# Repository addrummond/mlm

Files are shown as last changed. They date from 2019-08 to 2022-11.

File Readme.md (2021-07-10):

# Mimimalist Light Meter

    

## User manual

The user manual is [here](https://github.com/addrummond/mlm/blob/master/manual/manual.md).

## Overview

This is a simple ambient light meter using a Liteon LTR-303ALS light sensor and
an EFM32 Tiny Gecko ARM microcontroller. It is powered by a single CR2032 coin cell.
The firmware is written in C and the PCB is designed using KiCad. Readings are
displayed using a circle of 24 LEDs, with two additional LEDs indicating ±⅓ stop
adjustments. The user interface consists of three touch sensitive pads.

The goal of the project is to make available a simple, compact and inexpensive
light meter suitable for analogue photography. 

Dimensions: 87×56x7.5mm

The bottom side of the PCB (the side with no components mounted) is intended to
be used as the top panel of the case. This works best with a standard 1.6mm PCB
thickness.

The case is designed for 3D printing. It's best to use multi-jet fusion, as PLA
and ABS are usually not very light tight. (You could use PLA/ABS and then paint
the inside of the case black.) The STL file and Fusion 360 design for the case
are in the `case` directory. The PCB attaches to the case using five M1.6 4mm
countersunk screws. The dimples under the LEDs should be painted white and then
given a gloss varnish. A 10×10×2mm piece of transparent acrylic should be glued
in place over the sensor window. (If you don't add this, adjust
`WINDOW_ATTENUATION_STOPS` in `config.h`.)

The device functions as a reflective light meter. The same design could be
adapted for a spot meter or incident light meter by placing a lens or diffuser
over the sensor.

The LTR-303ALS integrates over a period of 50-400ms, which is far too long for
effective flash metering. A different design would therefore be required for
this purpose (probably using a discrete photodiode).

## Build notes

See `firmware/Readme.md` for notes on the dev toolchain.

Note that a recent (as of June 2020) development version of KiCad will be
required to open the board and schema files. Version 5.99.0-3928-g3c8396cd0 is
known to work. Each component in the schematic has a `MAN` (manufacturer) and
`MPN` (manufacturer part number) property.

I recommend using the [interactive BOM](https://github.com/openscopeproject/InteractiveHtmlBom) plugin for KiCad to aid manual placement of components.

## Known issue

* LEDs a little dim in bright daylight.

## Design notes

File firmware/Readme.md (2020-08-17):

## Development notes

The project builds using the
[GNU ARM embedded toolchain](https://developer.arm.com/tools-and-software/open-source-software/developer-tools/gnu-toolchain/gnu-rm/downloads)
and GNU make.

Production build:

```sh
cd firmware
make out.elf
```

Development build:

```sh
cd firmware
DEBUG=1 make out.elf
```

[RTT](https://www.segger.com/products/debug-probes/j-link/technology/about-real-time-transfer/)
is enabled in development builds.

Other environment variables:

* `DEBUG_DEEP_SLEEP=1` Reduces the time before the device enters deep sleep mode and shows a special pattern of LEDs before it does so.

* `NOGRACE=1` Removes the grace period before initial calibration (i.e. the period where the f8 LED is turned on after
power up). This is the default behavior when `DEBUG=1`.

* `GRACE=1` Overrides the aforementioned default behavior when `DEBUG=1`.

* `NO_RTT=1` Disables RTT (already disabled unless `DEBUG=1`).

* `LEDS_WRONG_WAY_ROUND=1` Set this if you have soldered all of the LEDs the 'wrong' way round. (As every LED lead is connected to a GPIO pin, it does not really matter which way round the LEDs are as long as they have a consistent orientation.)

## Debugging using JLink

I have been using the built-in JLink debugger of the [STK3200](https://www.silabs.com/products/development-tools/mcu/32-bit/efm32-zero-gecko-starter-kit).
These instruction should work for other SiLabs EFM32 series dev kits and for a real JLink probe.
When using one of the SiLabs dev kits, you'll first have to open up Simplicity Studio
and set the debug mode of the kit to 'out'.
You can download the JLink command line tools from [Segger's website](https://www.segger.com/downloads/jlink/#J-LinkSoftwareAndDocumentationPack).

Start JLink GDB server as follows:

    JLinkGDBServer -if SWD -Device EFM32TG108F32

Start gdb using

    arm-none-eabi-gdb

Commands for setting up semihosting are in `.gdbinit` in the `firmware` dir.
They'll be run automatically if you start GDB from within this dir.

Use RTT (https://www.segger.com/jlink-rtt.html) to log debug output. See
functions defined in firmware/rrt/SEGGER_RTT.h (e.g. `SEGGER_RTT_printf`).
RTT functions are included via firmware/rtt.h which provides an rtt_init()
function that wraps RTT initialization logic and stubs for RTT functions
when DEBUG mode is off.

To view RTT output:

    JLinkRTTClient

It seems to hook up with the JLink GDB server without the aid of any
parameters.

## Notes

* An unfortunate feature of the TPS610981 boost converter is that it has a
  tendency to misbehave during startup if there is an initial current spike and
  the power source has a high impedance. Coin cells, especially when at less
  than full capacity, have a relatively high impedance. I am still not sure
  exactly what happens, but the issue appears to be the same (unsolved) one that
  you can read about in [this forum
  post](http://e2e.ti.com/support/power-management/f/196/t/827996?TPS610981-Converter-in-latch-up-mode).
  From the point of view of using the device normally, I believe that I've
  solved this problem by bumping up the input capacitance slightly and making
  firmware changes to reduce current spiking on startup. However, when the
  debugger is connected, things are less predictable. I recommend using the 3.3V
  power out of the STK3200 while programming and debugging the device. (Just
  attach a crocodile clip to the coin cell retainer.) If you really want to use
  battery power while debugging, it's best to power up the device first and then
  connect the debugging leads. Even then, you may occasionally find that the
  TPS610981 gets into a weird state. If this happens, just remove the cell. In
  this state, the cell appears to be effectively shorted, so it can take it a
  little while to recover.

* It is necessary to do a `monitor reset` and `monitor halt` before loading new
firmware, since otherwise things like counters and interrupts can get screwed
up even though most of the code appears to run normally.

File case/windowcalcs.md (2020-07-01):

**Note**: These calculations are for a larger window than the one in the current design. See `case/fov/fov/__init__.py` for up to date calculations.

```
              ↔ 10mm
      -------------------- <-  upper surface of window
    2mm ↕     ↔ 7.2mm
        ---------------    <- lower surface of window
              |
       3.4mm↕ |  
 sensor ->  __|__ ↔ 0.305mm
            |   | ↕ 0.7mm
---------------------------------  <- pcb surface
```

Angle of view (half angle):

```
atan((7.2/2)/3.4) = 46.637°
```

Refractive indices:

```
air: 1.00029
acrylic: 1.4901
```

Refraction example:

```
angle of incidence = 40°
angle of refraction = 25.5626°
d = 2 * tan(25.5626°) = 0.957mm
```

Conclusion: effect of refraction should be negligible.

The LTR303 datasheet has a graph of relative responsivity against viewing angle.
Approximately 27.18% of the area of this graph is outside the 46.637° viewing
angle allowed by the window.

```
log2(1 + 0.2718) = 0.3468
```

Thus, the estimated attenuation from the restrictions imposed on angle of
view by the window is 0.3468 stops.

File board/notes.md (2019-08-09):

LED:

https://www.digikey.co.uk/product-detail/en/samsung-semiconductor-inc/SCP8RT78HPL1RLS06E/1510-1497-1-ND/6052660

https://www.digikey.co.uk/product-detail/en/osram-opto-semiconductors-inc/GW-SBLMA2.EM-HPHR-XX57-1-65-R18/475-3224-1-ND/6569722

35mm diameter circle (24 LEDs):

(0, 100.0, 82.5)
(345, 104.52933328929412, 83.0962980399413)
(330, 108.75, 84.84455543377233)
(315, 112.37436867076458, 87.62563132923542)
(300, 115.15544456622767, 91.25)
(285, 116.9037019600587, 95.47066671070588)
(270, 117.5, 100.0)
(255, 116.9037019600587, 104.52933328929412)
(240, 115.15544456622767, 108.75)
(225, 112.37436867076458, 112.37436867076458)
(210, 108.75, 115.15544456622767)
(195, 104.52933328929412, 116.9037019600587)
(180, 100.0, 117.5)
(165, 95.47066671070588, 116.9037019600587)
(150, 91.25, 115.15544456622769)
(135, 87.62563132923542, 112.37436867076458)
(120, 84.84455543377233, 108.75)
(105, 83.0962980399413, 104.52933328929412)
(90, 82.5, 100.0)
(75, 83.0962980399413, 95.4706667107059)
(60, 84.84455543377233, 91.25)
(45, 87.62563132923542, 87.62563132923542)
(30, 91.25, 84.84455543377233)
(15, 95.47066671070588, 83.0962980399413)

https://www.digikey.co.uk/product-detail/en/silicon-labs/EFM32TG210F8-QFN32/336-4548-2-ND/2508074

45 x 73
5 x 81

battery clip:

https://www.digikey.co.uk/product-detail/en/mpd-memory-protection-devices/BK-6219-TR/BK-6219-TR-ND/8119239

EFM32TG108

CR2016 cell holder

https://www.digikey.com/product-detail/en/mpd-memory-protection-devices/BLP2016SM-GTR/BLP2016SM-GCT-ND/5430470

Neat looking boost converter:

http://www.farnell.com/datasheets/71091.pdf

Very cheap 0603 LED:

https://www.digikey.co.uk/product-detail/en/wurth-electronics-inc/150060RS75000/732-4978-1-ND/4489899

Set ISO
Set aperture
Set shutter speed

Fix one; other two vary via slider.

Showing an exposure:

LEDs for relevant aperture and shutter speed are on.
LED for ISO flashes.

Compensation shown by

## Dimension stuff

Top layer component heights:

    EFM32 0.95 (max assuming 0.05mm tolerance)
    button height above board 0.65
    protrusion from top plate for button: 0.2

Bottom layer component heights:

    0.7 (light sensor)
    2.28 (battery clip max within tolerance)
    USE 2.6 mm standoff

PCB thickness:

    0.65 (assuming 0.05mm tolerance)

Total height:

    3.88mm

With 1mm case side thickness:

    5.88mm

Screws:

    https://www.accu.co.uk/en/binding-screws/72058-SBI-4-40-1-8-A2
    https://www.accu.co.uk/en/hexagon-nuts/36760-HPN-4-40-A2
    https://www.mouser.co.uk/ProductDetail/Keystone-Electronics/4881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

    |  board 0.6mm
    |
    ------
    |  screw hole thing 0.92mm
    |
    |
    |
    ------
    |
    |  gap (0)
    |
    ------
    |  rest 0.38mmm
    |
    |
    -----
    |
    |  screw head within floor extension 0.98mm
    |
    ------
    |
    |  screw head within floor 0.75mm 1.73mm
    |

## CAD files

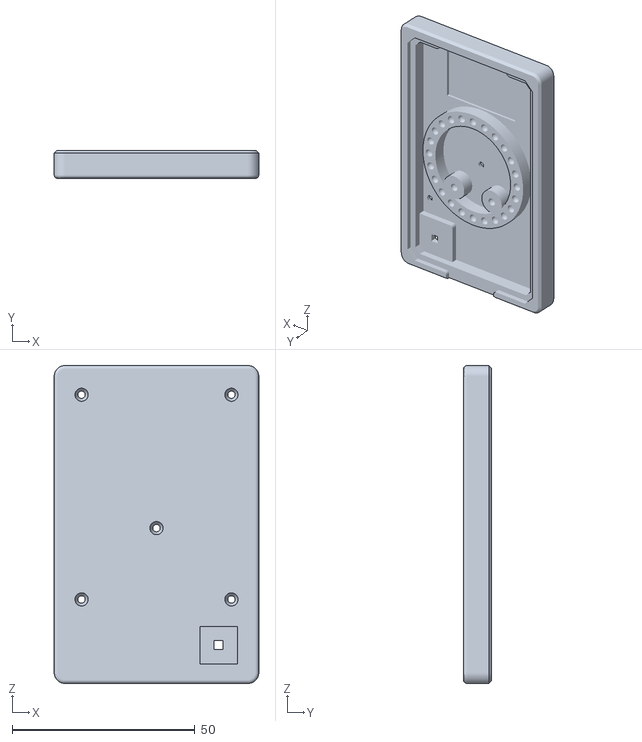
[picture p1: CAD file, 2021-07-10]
case/case.stl
56.0 x 7.70 x 87.0

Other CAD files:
case/case.f3d

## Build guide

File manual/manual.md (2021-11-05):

# Manual

## Overview

**Mode:** reflective

**Range:** EV -3.5 to 19 at ISO 100

**Field of view:** 40° (horizontal FOV of 50mm lens on full frame)

## Turning the meter on

The meter does not have an on/off switch. It is always ready to detect a press
of the center pad. (It cannot be worken up by pressing the left or right pads.)

Due to careful use of low energy sleep modes, the battery drains very slowly
when the meter is not in use.

After around an hour without use, the meter goes into a deeper sleep mode.
To wake the meter from this mode, you may need to hold down the center pad for
up to one second.

## Basic operation

Take a reading by pointing the sensor window towards the subject and 
pressing and holding the center pad.

While the reading is in process, the lights on the wheel cycle rapidly. Once the
reading is complete, the lights stop cycling and the reading is displayed.

Let go of the center pad once the reading is complete.

Read off the aperture and shutter speed.

## Battery

The meter is powered by a single CR2032 coin cell. The cell should be inserted
with the positive side facing away from the circuit board.

When a new battery is inserted, the light for f8 will turn on for around 10
seconds. When this light goes out, initial calibration of the touch pads is
performed (which takes a fraction of a second). For best results, rest the meter
on the case while the light is still on, and wait for a second after the light
goes out before touching the meter.

## Changing the aperture and shutter speed.

While a reading is displayed, tap the left or right pad to move
beetween equivalent exposures. For example, if the exposure shown is 1/60 at f8,
tapping the left pad will switch to 1/125 at f5.6.

Out of the box, the first reading is displayed with the aperture fixed at f8
(unless a very bright or very dark scene makes this impossible). On subsequent
readings, the meter attempts to preserve the last selected aperture.

## Third stops

The two lights inside the wheel indicate changes of ±⅓ stop. The light on the
left means “go ⅓ stop counterclockwise”; the light on the right
means “go ⅓ stop clockwise”.

**Example:** the exposure shown is 1/60 at f8 and the right light is on. This
indicates that the following are correct exposures:

* 1/80 at f8 (adjusting the shutter speed by ⅓ stop), and
* 1/60 at f9 (adjusting the aperture by ⅓ stop).

## Reading display timeout

After a reading has been displayed for around 20 seconds, the meter will
automatically sleep. Tap the center pad to wake the meter up and display the
last reading.

## Changing the ISO

The meter is set to ISO 100 by default. To change the ISO, press the left and
right pads simultaneously while the meter is displaying a reading. The currently
set ISO is indicated by a single pulsing light. Tap the left and right pads to
adjust, then tap the center pad to confirm and return to the reading display.

All ISO numbers shown on the inside of the wheel are full stop ISOs. Third stop
ISOs are shown as bullets. You can select a third stop ISO that has no
corresponding bullet by selecting the nearest full stop ISO and then holding the
left or right pad until one of the ±⅓ stop indication lights turns on. The left
light means “go ⅓ stop counterclockwise” (i.e. decrease the ISO number
slightly), while the right light means “go ⅓ stop clockwise” (i.e. increase the
ISO number slightly).

When a reading is in progress, one light stays on uninterrupted while the others
cycle. This light indicates the currently selected ISO (or the nearest full stop
ISO to it).

## Special display of low light exposures

Using two indicator lights (one for aperture and one for shutter speed), the
wheel can show exposures down to -⅓EV at any given ISO. As the lower range of
the meter is -3.5EV at ISO 100, this means that at ISOs below 1600, the EV can
be low enough that no corresponding exposure can be displayed in the usual way.
In this circumstance, the meter indicates exposures longer than one second by
turning on three shutter speed lights rather than one. The number corresponding
to the middle light should be interpreted as a number of seconds. For example,
if the lights for 2, 4 and 8 are on, this indicates an exposure of four
seconds.

## Out of range indication

If the scene is too bright or too dark for the meter, the three lights at the
top of the wheel (corresponding to f5.6, f8 and f11) turn on simultaneously.

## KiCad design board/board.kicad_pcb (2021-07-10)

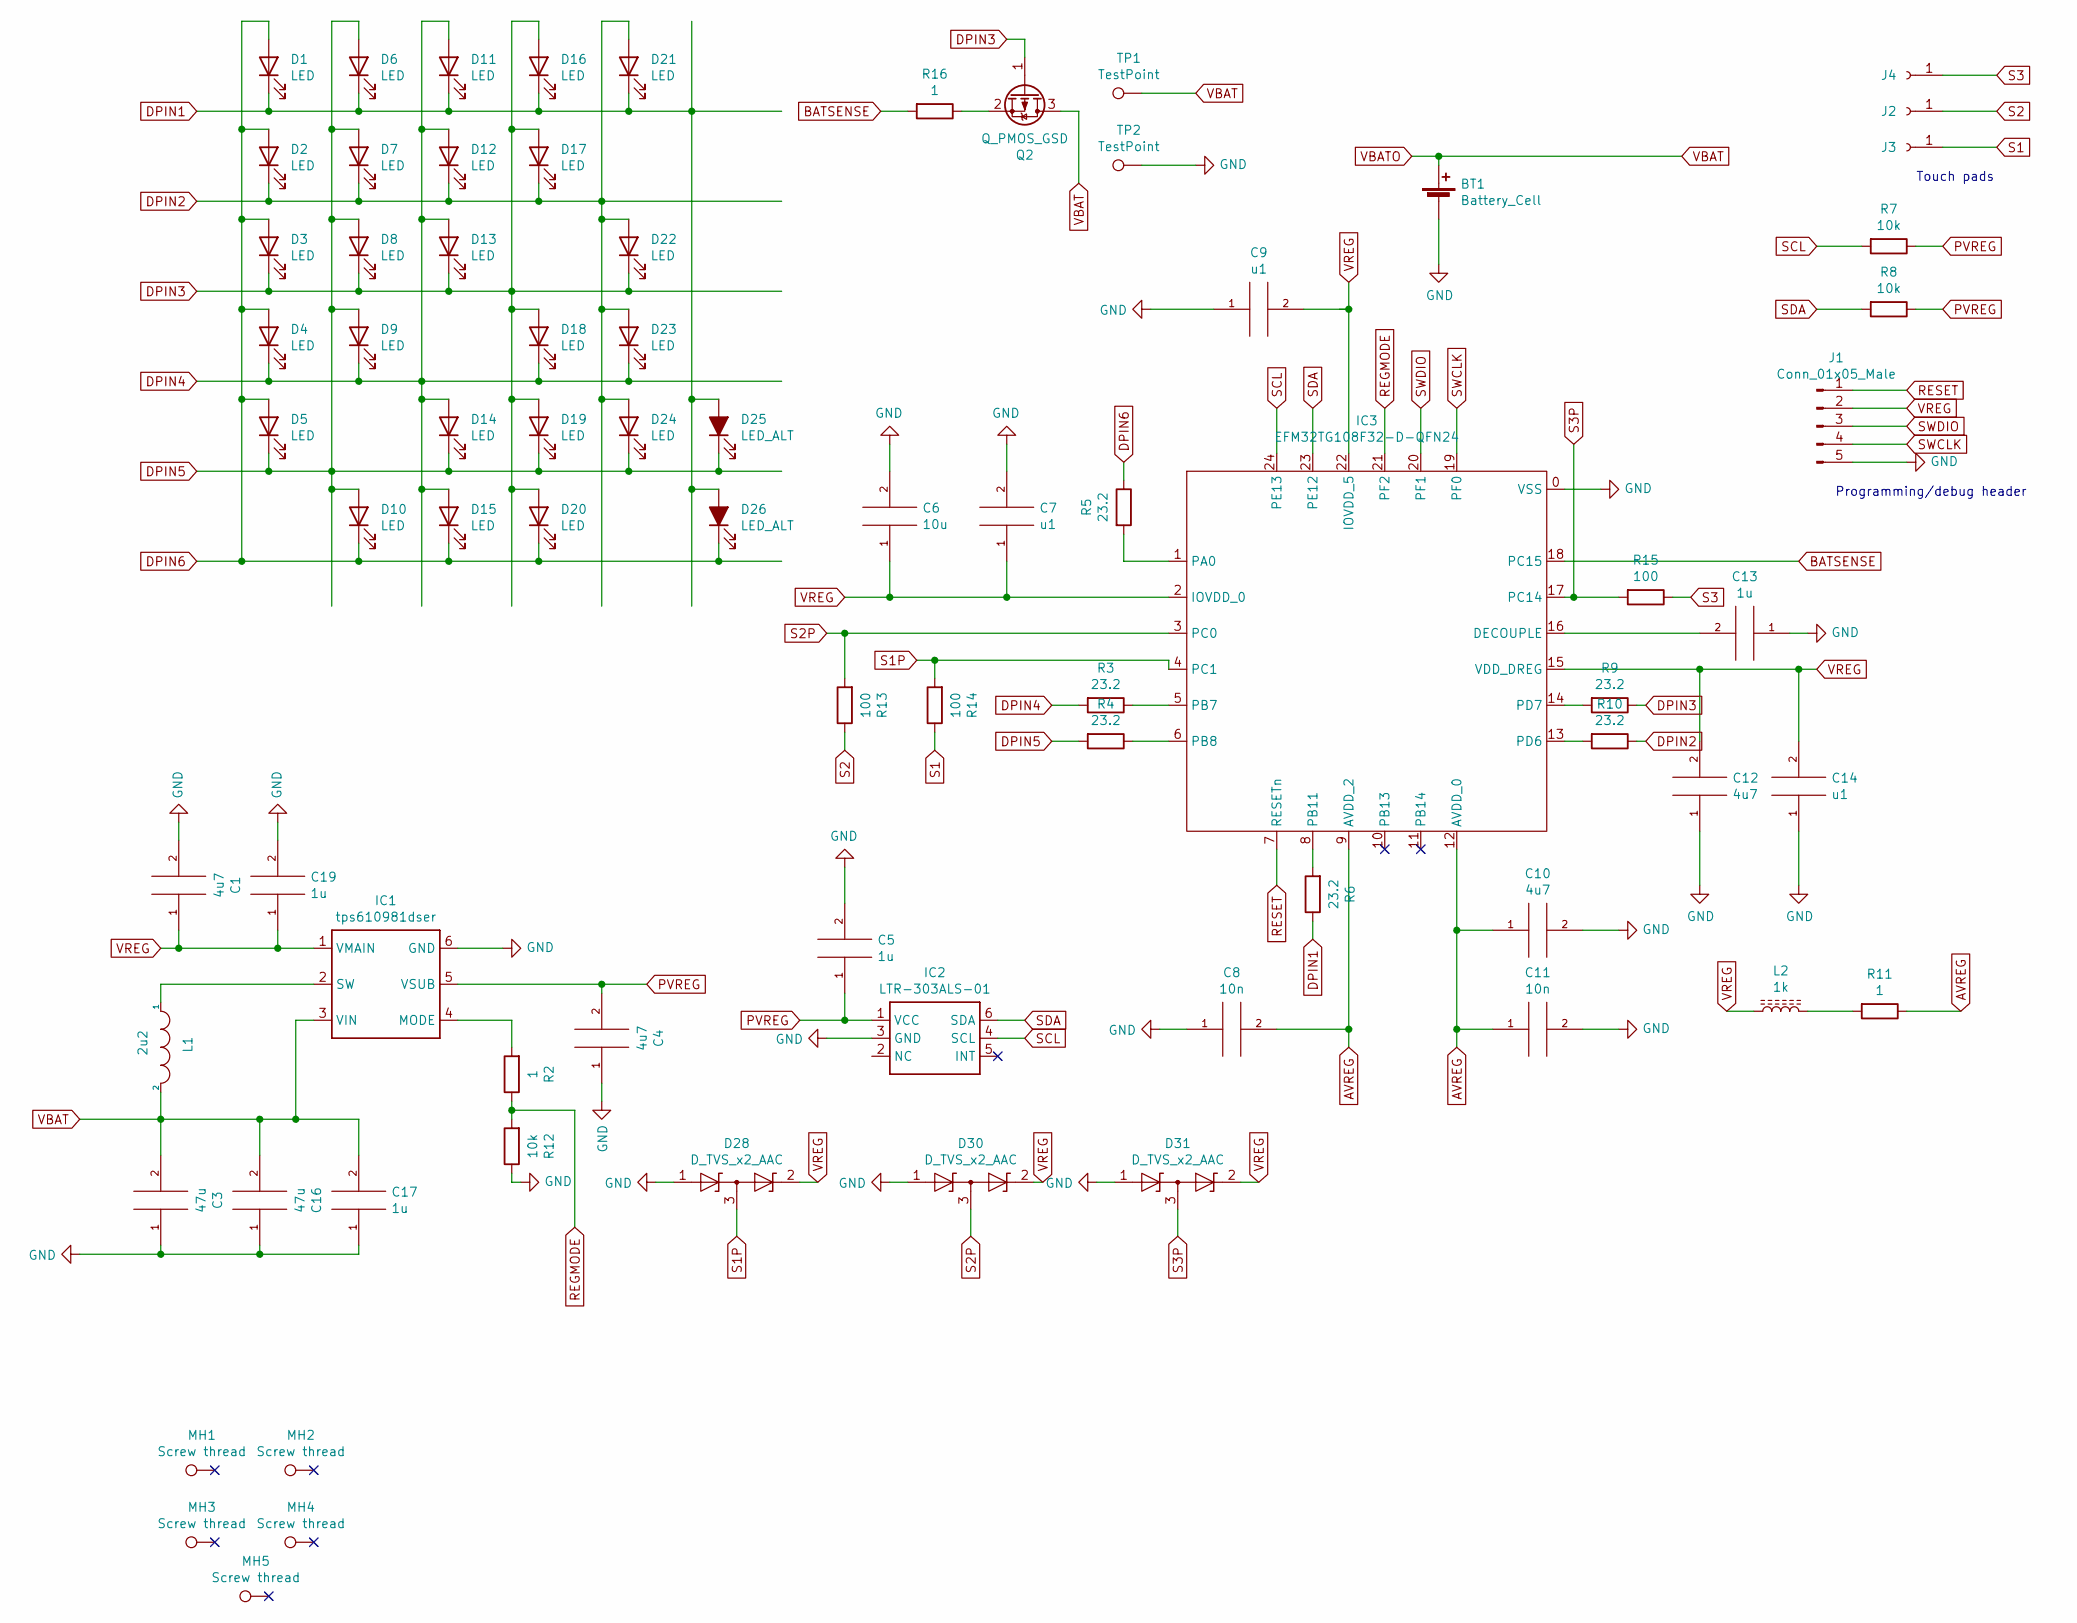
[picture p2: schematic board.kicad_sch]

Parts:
BT1: Battery_Cell; BK-5067; MPN BK-5067
C1, C4, C10, C12: 4u7; 0603; MPN C0603C475K9PAC7411
C3, C16: 47u; 0603; MPN GRM188R60G476ME15D
C5, C13, C17, C19: 1u; 0603; MPN CL10B105KP8NNNC
C6: 10u; 0603; MPN JMK107ABJ106MA-T
C7, C9, C14: u1; 0603; MPN 885012206020
C8, C11: 10n; 0603; MPN CL10B103KB8NNNC
D1, D2, D3, D4, D5, D6, D7, D8, D9, D10, D11, D12, D13, D14, D15, D16, D17, D18, D19, D20, D21, D22, D23, D24: LED; dual0402; MPN IN-S42BT5B
D25, D26: LED_ALT; dual0402; MPN IN-S42BT5B
D28, D30, D31: D_TVS_x2_AAC; SOT-23; MPN BAS70-04-TP
IC1: tps610981dser; tps610986; MPN TPS610981DSER
IC2: LTR-303ALS-01; LTR303ALS01; MPN LTR-303ALS-01
IC3: EFM32TG108F32-D-QFN24; EFM32TG108_QFN24; MPN EFM32TG108F32-QFN24
J1: Conn_01x05_Male; M20-7910542R; MPN M20-7910542R
J2, J3, J4: TOUCHPAD
L1: 2u2; NRS4010T2R2MDGG; MPN NRS4010T2R2MDGG
L2: 1k; 0805; MPN BLM21BD102SN1D
MH1, MH2, MH3, MH4, MH5: Screw thread; 97730306330R; MPN 97730306330R
Q2: Q_PMOS_GSD; SOT-23; MPN SI2329DS-T1-GE3
R2, R11, R16: 1; 0603; MPN ERJ3RQF1R0V
R3, R4, R5, R6, R9, R10: 23.2; 0603; MPN ERJ-3EKF23R2V
R7, R8, R12: 10k; 0603; MPN RNCP0603FTD10K0
R13, R14, R15: 100; 0603; MPN RC0603FR-07100RL
TP1, TP2: TestPoint; TestPoint_Pad_D1.5mm

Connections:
AVREG: C8.2, C10.1, C11.1, IC3.9 (AVDD_2), IC3.12 (AVDD_0), R11.1
BATSENSE: IC3.18 (PC15), R16.2
DPIN1: D1.1 (K), D6.1 (K), D11.1 (K), D16.1 (K), D21.1 (K), D25.2 (A), D26.2 (A), R6.1
DPIN2: D2.1 (K), D7.1 (K), D12.1 (K), D17.1 (K), D21.2 (A), D22.2 (A), D23.2 (A), D24.2 (A), R10.1
DPIN3: D3.1 (K), D8.1 (K), D13.1 (K), D16.2 (A), D17.2 (A), D18.2 (A), D19.2 (A), D20.2 (A), D22.1 (K), Q2.1 (G), R9.1
DPIN4: D4.1 (K), D9.1 (K), D11.2 (A), D12.2 (A), D13.2 (A), D14.2 (A), D15.2 (A), D18.1 (K), D23.1 (K), R3.2
DPIN5: D5.1 (K), D6.2 (A), D7.2 (A), D8.2 (A), D9.2 (A), D10.2 (A), D14.1 (K), D19.1 (K), D24.1 (K), D25.1 (K), R4.2
DPIN6: D1.2 (A), D2.2 (A), D3.2 (A), D4.2 (A), D5.2 (A), D10.1 (K), D15.1 (K), D20.1 (K), D26.1 (K), R5.1
GND: BT1.2 (-), C1.2, C3.1, C4.1, C5.2, C6.2, C7.2, C8.1, C9.1, C10.2, C11.2, C12.1, C13.1, C14.1, C16.1, C17.1, C19.2, D28.1 (A1), D30.1 (A1), D31.1 (A1), IC1.6 (GND), IC2.3 (GND), IC3.0 (VSS), J1.5, R12.1, TP2.1
unnamed: C13.2, IC3.16 (DECOUPLE)
unnamed: IC1.2 (SW), L1.1
unnamed: IC1.4 (MODE), R2.2
unnamed: IC3.1 (PA0), R5.2
unnamed: IC3.5 (PB7), R3.1
unnamed: IC3.6 (PB8), R4.1
unnamed: IC3.8 (PB11), R6.2
unnamed: IC3.13 (PD6), R10.2
unnamed: IC3.14 (PD7), R9.2
unnamed: L2.2, R11.2
unnamed: Q2.2 (S), R16.1
PVREG: C4.2, C5.1, IC1.5 (VSUB), IC2.1 (VCC), R7.1, R8.1
REGMODE: IC3.21 (PF2), R2.1, R12.2
RESET: IC3.7 (RESETn), J1.1
S1: J3.1, R14.1
S1P: D28.3 (common), IC3.4 (PC1), R14.2
S2: J2.1, R13.1
S2P: D30.3 (common), IC3.3 (PC0), R13.2
S3: J4.1, R15.1
S3P: D31.3 (common), IC3.17 (PC14), R15.2
SCL: IC2.4 (SCL), IC3.24 (PE13), R7.2
SDA: IC2.6 (SDA), IC3.23 (PE12), R8.2
SWCLK: IC3.19 (PF0), J1.4
SWDIO: IC3.20 (PF1), J1.3
VBAT: BT1.1 (+), C3.2, C16.2, C17.2, IC1.3 (VIN), L1.2, Q2.3 (D), TP1.1
VREG: C1.1, C6.1, C7.1, C9.2, C12.2, C14.2, C19.1, D28.2 (A2), D30.2 (A2), D31.2 (A2), IC1.1 (VMAIN), IC3.2 (IOVDD_0), IC3.15 (VDD_DREG), IC3.22 (IOVDD_5), J1.2, L2.1

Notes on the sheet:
Programming/debug header
Touch pads

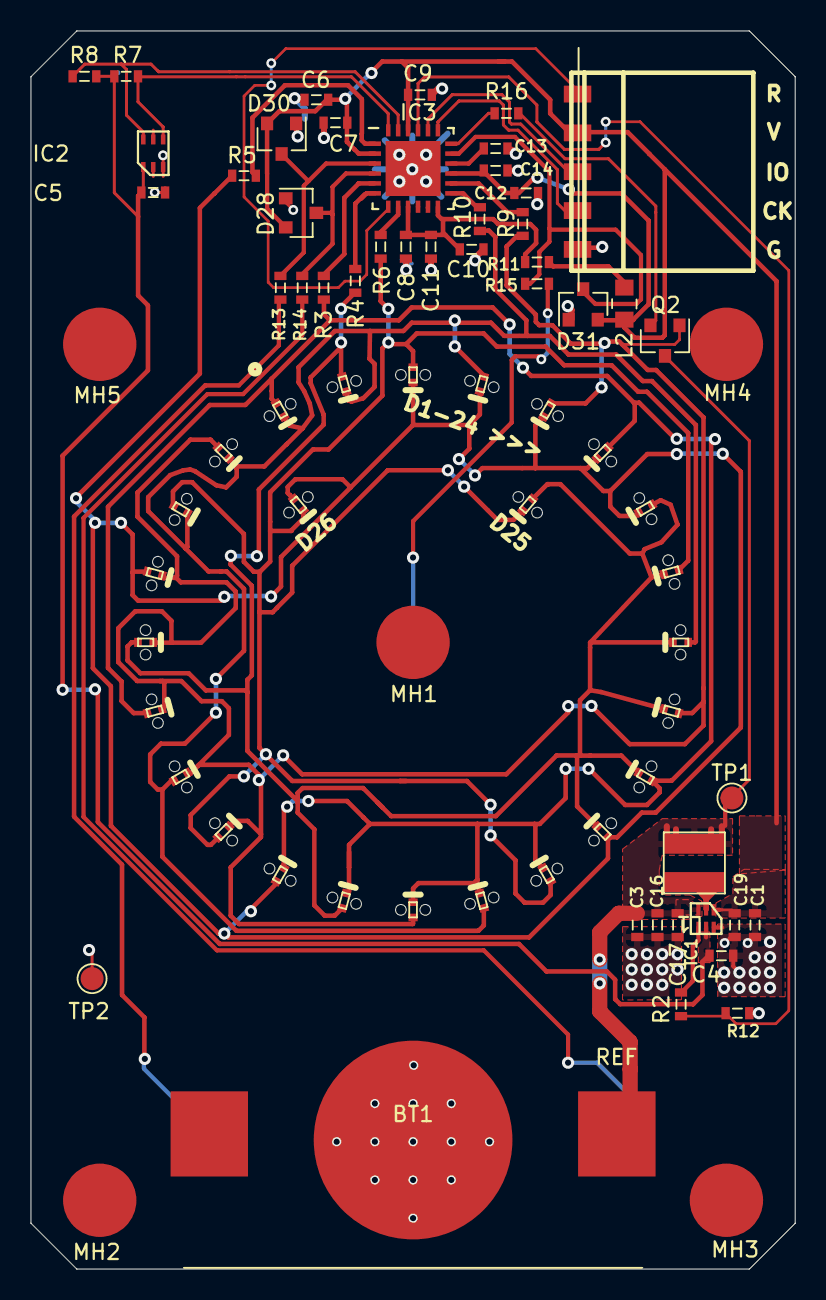
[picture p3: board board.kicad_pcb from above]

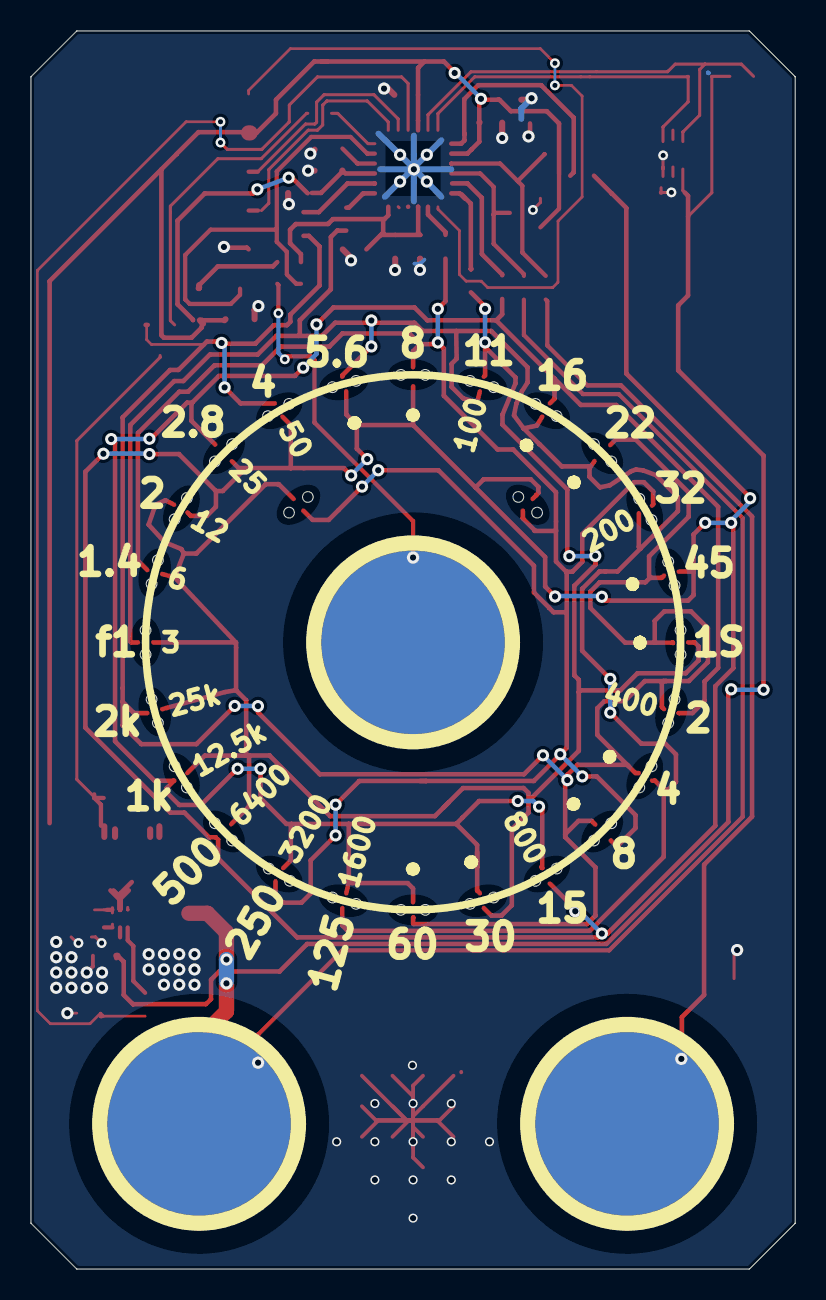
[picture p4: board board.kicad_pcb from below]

Board: 2 copper layers, 50.0 x 81.0 mm, 78 parts (29 on the bottom side), 35 nets.

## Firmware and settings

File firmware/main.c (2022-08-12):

#include <config.h>

#include <batsense.h>
#include <capsense.h>
#include <em_acmp.h>
#include <em_chip.h>
#include <em_cmu.h>
#include <em_dbg.h>
#include <em_emu.h>
#include <em_device.h>
#include <em_emu.h>
#include <em_gpio.h>
#include <em_pcnt.h>
#include <em_prs.h>
#include <em_rmu.h>
#include <em_rtc.h>
#include <em_timer.h>
#include <em_wdog.h>
#include <init.h>
#include <iso.h>
#include <leds.h>
#include <myemu.h>
#include <pins.h>
#include <rtc.h>
#include <rtt.h>
#include <sensor.h>
#include <state.h>
#include <stdbool.h>
#include <stdint.h>
#include <tempsensor.h>
#include <time.h>
#include <units.h>
#include <util.h>

#ifdef TEST_MAIN
int test_main(void);
#endif

static void go_into_deep_sleep()
{
    SEGGER_RTT_printf(0, "Enter deep sleep (unless in DEBUG mode).\n");

    CMU_ClockEnable(cmuClock_CORELE, true);

    EMU_EM23Init_TypeDef dcdcInit = EMU_EM23INIT_DEFAULT;
    EMU_EM23Init(&dcdcInit);

    RTC_Enable(false);

    WDOG_Init_TypeDef wInit = {
        .clkSel = wdogClkSelULFRCO,
        .debugRun = true,
        .em2Run = true,
        .em3Run = true,
        .em4Block = true,
        .enable = true,
        .lock = false,
        .perSel = wdogPeriod_1k, // 1k 1kHz periods should give ~4 seconds in EM3
        .swoscBlock = false
    };

    WDOGn_Init(WDOG, &wInit);
    WDOGn_Feed(WDOG);

    RMU->CTRL &= ~0b111;
    RMU->CTRL |= 1; // limited watchdog reset

    my_emu_enter_em3(false);
}

static void go_into_deep_sleep_with_indication()
{
    // A visual indication that it's going into deep sleep mode is sometimes
    // useful for debugging.
#ifdef DEBUG_DEEP_SLEEP
    leds_all_off();
    leds_on(0b111);
    uint32_t start = leds_on_for_cycles;
    while (leds_on_for_cycles - start < RTC_RAW_FREQ)
        ;
    leds_all_off();
#endif

    go_into_deep_sleep();
}

static void go_into_fake_deep_sleep_with_indication()
{
    // A visual indication that it's going into fake deep sleep mode is sometimes
    // useful for debugging.
#ifdef DEBUG_DEEP_SLEEP
    leds_all_off();
    leds_on(0b11);
    uint32_t start = leds_on_for_cycles;
    while (leds_on_for_cycles - start < RTC_RAW_FREQ)
        ;
    leds_all_off();
#endif

    le_capsense_slow_scan();
}

static void maybe_sleep_deeper()
{
    static const int32_t DEEP_SLEEP_TIMING_FUDGE_FACTOR_NUMERATOR = 6;
    static const int32_t DEEP_SLEEP_TIMING_FUDGE_FACTOR_DENOMINATOR = 5;

    static const int32_t deep_sleep_timeout_seconds =
#ifdef DEBUG_DEEP_SLEEP
        DEEP_SLEEP_TIMEOUT_SECONDS_DEBUG_MODE;
#else
        DEEP_SLEEP_TIMEOUT_SECONDS;
#endif

#ifndef DEBUG
    if ((g_state.deep_sleep_counter++) * DEEP_SLEEP_TIMING_FUDGE_FACTOR_NUMERATOR / DEEP_SLEEP_TIMING_FUDGE_FACTOR_DENOMINATOR > deep_sleep_timeout_seconds/LE_CAPSENSE_CALIBRATION_INTERVAL_SECONDS) {
        // We've been sleeping for a while now and nothing has happened.
        // Time to go into deep sleep.
#ifdef DISABLE_DEEP_SLEEP
        go_into_fake_deep_sleep_with_indication();
#else
        go_into_deep_sleep_with_indication();
#endif
    }
#endif
}

static void handle_MODE_JUST_WOKEN()
{
    if (! g_state.watchdog_wakeup) {
        while (! check_lesense_irq_handler()) {
            maybe_sleep_deeper();

            recalibrate_le_capsense();
            SEGGER_RTT_printf(0, "EM2 snooze after calib.\n");
            my_emu_enter_em2(true); // true = restore oscillators, clocks and voltage scaling
            SEGGER_RTT_printf(0, "Woken up [2]!\n");
        }

        disable_le_capsense();

        int v = battery_voltage_in_10th_volts();
        g_state.bat_known_healthy = (v >= 27);
        SEGGER_RTT_printf(0, "BKH %u %u\n", v, g_state.bat_known_healthy);
#ifdef DEBUG
        g_state.bat_known_healthy = false;
#endif

    } else {
        PCNT_Reset(PCNT0);
        reset_lesense_irq_handler_state();
        reset_led_state();
        reset_capsense_state();
        SEGGER_RTT_printf(0, "Watchdog wake\n");
    }

    g_state.watchdog_wakeup = false;
    g_state.deep_sleep_counter = 0;

    // If it was a brief tap on the button, go to AWAKE_AT_REST.
    // If they've held the button down for a little bit,
    // start doing a reading. If it was a double tap, go to
    // ISO / exposure set mode.
    setup_capsense();
    press p = get_pad_press(CENTER_BUTTON, LONG_PRESS_MS);
    disable_capsense();

    rtc_init();

    if (p == PRESS_HOLD) {
        g_state.mode = MODE_DOING_READING;
    } else if (p == PRESS_TAP) {
        // It was just a tap.
        g_state.last_reading_flags |= LAST_READING_FLAGS_FRESH;
        g_state.mode = MODE_AWAKE_AT_REST;
    } else {
        SEGGER_RTT_printf(0, "Unknown but\n");
    }
}

static void handle_MODE_AWAKE_AT_REST()
{
    // Display the current reading, if any.
    if (fresh_reading_is_saved()) {
        g_state.mode = MODE_DISPLAY_READING;
        g_state.last_reading_flags &= ~(int32_t)LAST_READING_FLAGS_FRESH;
    } else {
        g_state.mode = MODE_SNOOZE;
    }
}

static void handle_MODE_SNOOZE()
{
    // Make sure LDO is off
    GPIO_PinModeSet(REGMODE_PORT, REGMODE_PIN, gpioModeDisabled, 0);

    setup_le_capsense_sleep();

    SEGGER_RTT_printf(0, "EM2 for snooze\n");
    my_emu_enter_em2(true); // true = restore oscillators, clocks and voltage scaling

    SEGGER_RTT_printf(0, "Woken!\n");
    g_state.mode = MODE_JUST_WOKEN;
}

static int shift_exposure_wheel(int n, int *ap_index, int *ss_index, bool using_long_ss)
{
    int ap = *ap_index;
    int ss = *ss_index;
    while (n != 0) {
        if (n > 0) {
            if (ap == AP_INDEX_MAX)
                break;
            if ((using_long_ss && ss == SS_INDEX_LONG_MIN) || (!using_long_ss && ss == SS_INDEX_MIN))
                break;
            ++ap;
            --ss;
            --n;
        } else {
            if (ss == SS_INDEX_MAX)
                break;
            if (ap == AP_INDEX_MIN)
                break;
            ++ss;
            --ap;
            ++n;
        }
        *ap_index = ap;
        *ss_index = ss;
    }

    return n;
}

static void handle_MODE_DISPLAY_READING()
{
    int32_t iso = iso_dial_pos_and_third_to_iso(g_state.iso_dial_pos, g_state.iso_third);
    int ap_index, ss_index, third;
    ev_iso_aperture_to_shutter(g_state.last_reading_ev, iso, g_state.last_ap, &ap_index, &ss_index, &third);
    bool using_long_ss = ss_index < SS_INDEX_MIN;
    SEGGER_RTT_printf(0, "ISOi=%u, api=%s%u, ssi=%s%u\n", iso, sign_of(ap_index), iabs(ap_index), sign_of(ss_index), iabs(ss_index));

    leds_all_off();
    set_led_throb_mask(0);
    set_led_flash_mask(0);
    leds_on(led_mask_for_reading(ap_index, ss_index, third));

    setup_capsense();

    uint32_t base_cycles = leds_on_for_cycles;
    int zero_touch_position = INVALID_TOUCH_POSITION;
    uint32_t touch_counts[] = { 0, 0, 0 };
    bool in_center_button_dead_zone = true;
    uint32_t ellapsed;
    for (unsigned i = 0;; ++i) {
        delay_ms_cyc_prepare {
            get_touch_count(0, 0, 0); // clear any nonsense value
        }
        ellapsed = delay_ms_cyc_loop(PAD_COUNT_MS);

        uint32_t count, chan;
        get_touch_count(&count, &chan, ellapsed);
        touch_counts[chan] = count;

        if (leds_on_for_cycles - base_cycles > (CENTER_BUTTON_DEAD_ZONE_MS * RTC_RAW_FREQ) / 1000)
            in_center_button_dead_zone = false;

        if (touch_counts[0] != 0 && touch_counts[1] != 0 && touch_counts[2] != 0) {
            int tp = get_touch_position(touch_counts[0], touch_counts[1], touch_counts[2]);
            
            if (tp == NO_TOUCH_DETECTED) {
                zero_touch_position = INVALID_TOUCH_POSITION;
            } else {
                base_cycles = leds_on_for_cycles;

                if (zero_touch_position == INVALID_TOUCH_POSITION) {
                    if (tp == LEFT_BUTTON || tp == RIGHT_BUTTON || tp == LEFT_AND_RIGHT_BUTTONS) {
                        // If we just have one of the left/right buttons, wait to see if the situation
                        // changes in the next split second.
                        if (tp != LEFT_AND_RIGHT_BUTTONS) {
                            uint32_t over_base = leds_on_for_cycles;
                            int misses = 0;
                            touch_counts[0] = 0, touch_counts[1] = 0, touch_counts[2] = 0;
                            for (unsigned j = 0;; ++j) {
                                delay_ms_cyc_prepare {
                                    get_touch_count(0, 0, 0); // clear any nonsense value
                                }
                                ellapsed = delay_ms_cyc_loop(PAD_COUNT_MS);

                                get_touch_count(&count, &chan, ellapsed);
                                touch_counts[chan] = count;

                                if (touch_counts[0] != 0 && touch_counts[1] != 0 && touch_counts[2] != 0) {
                                    int tp2 = get_touch_position(touch_counts[0], touch_counts[1], touch_counts[2]);
                                    if (tp2 == LEFT_AND_RIGHT_BUTTONS) {
                                        tp = tp2;
                                        break;
                                    }
                                    if (tp2 == NO_TOUCH_DETECTED) {
                                        ++misses;
                                        if (misses >= MISSES_REQUIRED_TO_BREAK_HOLD)
                                            break;
                                    } else {
                                        misses = 0;
                                    }
                                }

                                if (leds_on_for_cycles - over_base >= (DOUBLE_BUTTON_SLOP_MS * RTC_RAW_FREQ / 1000))
                                    break;

                                cycle_capsense();
                            }
                        }

                        if (tp == LEFT_AND_RIGHT_BUTTONS && get_pad_press(LEFT_AND_RIGHT_BUTTONS, ISO_LONG_PRESS_MS) == PRESS_HOLD) {
                            goto handle_double_button_press;
                        }
                        else {
                            int r = shift_exposure_wheel(tp == RIGHT_BUTTON ? 1 : -1, &ap_index, &ss_index, using_long_ss);
                            g_state.last_ap = ap_index;
                            uint32_t mask = led_mask_for_reading(ap_index, ss_index, third);
                            leds_change_mask(mask);
                            if (r != 0) {
                                uint32_t flash_mask = (mask & ~((1 << LED_MINUS_1_3_N) | (1 << LED_PLUS_1_3_N)));
                                set_led_flash_mask(flash_mask);
                                delay_ms_cyc(1000);
                                set_led_flash_mask(0);
                            }
                        }
                    } else if (tp == CENTER_BUTTON && ! in_center_button_dead_zone) {
                        goto handle_center_press;
                    }
                    zero_touch_position = tp;
                } else {
                    zero_touch_position = tp;
                }
            }            
        }

        if (leds_on_for_cycles - base_cycles >= DISPLAY_READING_TIME_SECONDS * RTC_RAW_FREQ) {
            SEGGER_RTT_printf(0, "Reading timeout\n");
            break;
        }

        cycle_capsense();
    }

    disable_capsense();
    leds_all_off();

    g_state.mode = MODE_SNOOZE;

    return;

handle_center_press:
    leds_all_off();
    press p = get_pad_press(CENTER_BUTTON, LONG_PRESS_MS);
    disable_capsense();
    if (p == PRESS_HOLD)
        g_state.mode = MODE_DOING_READING;
    else if (p == PRESS_TAP)
        g_state.mode = MODE_SNOOZE;
    return;

handle_double_button_press:
    leds_all_off();
    disable_capsense();
    g_state.mode = MODE_SETTING_ISO;
}

static void handle_MODE_SETTING_ISO()
{
    leds_all_off();

    uint32_t leds = 1 << iso_dial_pos_to_led_n(g_state.iso_dial_pos);
    set_led_throb_mask(leds);
    if (g_state.iso_third == -1)
        leds |= 1 << LED_MINUS_1_3_N;
    else if (g_state.iso_third == 1)
        leds |= 1 << LED_PLUS_1_3_N;
    leds_on(leds);

    setup_capsense();

    uint32_t base_cycles = leds_on_for_cycles;
    int zero_touch_position = INVALID_TOUCH_POSITION;
    uint32_t touch_counts[] = { 0, 0, 0 };
    for (;;) {
        delay_ms_cyc_prepare {
            get_touch_count(0, 0, 0);
        }
        uint32_t ellapsed = delay_ms_cyc_loop(PAD_COUNT_MS);
        uint32_t count, chan;
        get_touch_count(&count, &chan, ellapsed);
        touch_counts[chan] = count;

        if (touch_counts[0] != 0 && touch_counts[1] != 0 && touch_counts[2] != 0) {
            int tp = get_touch_position(touch_counts[0], touch_counts[1], touch_counts[2]);
            
            if (tp == NO_TOUCH_DETECTED) {
                zero_touch_position = INVALID_TOUCH_POSITION;
            } else {
                base_cycles = leds_on_for_cycles;

                if (zero_touch_position == INVALID_TOUCH_POSITION) {
                    if (tp == LEFT_BUTTON || tp == RIGHT_BUTTON) {
                        // Check if it's a tap or a hold, if we're on one
                        // of the ISOs that can be modified with +/- 1/3rd.
                        press p = PRESS_TAP;
                        bool cycled = false;
                        if ((tp == LEFT_BUTTON && iso_dial_pos_can_go_third_below(g_state.iso_dial_pos)) || (tp == RIGHT_BUTTON && iso_dial_pos_can_go_third_above(g_state.iso_dial_pos))) {
                            if (tp == LEFT_BUTTON) {
                                cycled = true;
                                cycle_capsense();
                            }
                        
                            p = get_pad_press(tp, ISO_LONG_PRESS_MS);
                        }

                        int mag = (tp == RIGHT_BUTTON ? 1 : -1);
                        if (p == PRESS_TAP) {
                            g_state.iso_third = 0;
                            g_state.iso_dial_pos += mag;
                            if (g_state.iso_dial_pos < 0)
                                g_state.iso_dial_pos += ISO_N_DIAL_POSITIONS;
                            else
                                g_state.iso_dial_pos %= ISO_N_DIAL_POSITIONS;
                        } else {
                            // Button press will only have registered as a hold if this is a thirdable point on the dial.
                            g_state.iso_third = mag;
                        }
                        
                        leds = 1 << iso_dial_pos_to_led_n(g_state.iso_dial_pos);
                        set_led_throb_mask(leds);
                        if (g_state.iso_third == -1)
                            leds |= 1 << LED_MINUS_1_3_N;
                        else if (g_state.iso_third == 1)
                            leds |= 1 << LED_PLUS_1_3_N;
                        leds_change_mask(leds);

                        SEGGER_RTT_printf(0, "ISO -> raw %u\n", iso_dial_pos_and_third_to_iso(g_state.iso_dial_pos, g_state.iso_third));

                        if (cycled) {
                            cycle_capsense();
                            cycle_capsense();
                        }
                    } else if (tp == CENTER_BUTTON) {
                        goto handle_center_press;
                    }
                    zero_touch_position = tp;
                } else {
                    zero_touch_position = tp;
                }
            }            
        }

        if (leds_on_for_cycles - base_cycles >= DISPLAY_READING_TIME_SECONDS * RTC_RAW_FREQ) {
            SEGGER_RTT_printf(0, "Reading timeout (ISO mode)\n");
            break;
        }

        cycle_capsense();
    }

    leds_all_off();
    disable_capsense();

    SEGGER_RTT_printf(0, "Enter MODE_SNOOZE\n");
    g_state.mode = MODE_SNOOZE;

    return;

handle_center_press:
    SEGGER_RTT_printf(0, "ISO button press\n");
    leds_all_off();
    press p = get_pad_press(CENTER_BUTTON, LONG_PRESS_MS);
    disable_capsense();
    if (p == PRESS_HOLD)
        g_state.mode = MODE_DOING_READING;
    else if (p == PRESS_TAP)
        g_state.mode = MODE_SNOOZE;
}

static uint32_t display_reading_interrupt_cycle_mask1;
static uint32_t display_reading_interrupt_cycle_mask2;
static uint32_t display_reading_interrupt_cycle_iso_mask;
static void display_reading_interrupt_cycle_interrupt_handler()
{
    if (leds_on_for_cycles % 16 != 0)
        return;

    if (leds_on_for_cycles % 32 != 0) {
        display_reading_interrupt_cycle_mask1 = (display_reading_interrupt_cycle_mask1 + 1) % LED_N_IN_WHEEL;
    }

    display_reading_interrupt_cycle_mask2 = (display_reading_interrupt_cycle_mask2 + 1) % LED_N_IN_WHEEL;

    leds_change_mask((1 << display_reading_interrupt_cycle_iso_mask) | (1 << (LED_N_IN_WHEEL - display_reading_interrupt_cycle_mask1 - 1)) | (1 << display_reading_interrupt_cycle_mask2));
}

static void handle_MODE_DOING_READING()
{
    // Light show while the reading is being done.
    leds_all_off();
    add_rtc_interrupt_handler(display_reading_interrupt_cycle_interrupt_handler);
    display_reading_interrupt_cycle_mask1 = 8;
    display_reading_interrupt_cycle_mask2 = 16;
    display_reading_interrupt_cycle_iso_mask = iso_dial_pos_to_led_n(g_state.iso_dial_pos);
    leds_on((1 << display_reading_interrupt_cycle_iso_mask) | (1 << display_reading_interrupt_cycle_mask1) | (1 << display_reading_interrupt_cycle_mask2));

    // Turn on the LDO to power up the sensor.
    GPIO_PinModeSet(REGMODE_PORT, REGMODE_PIN, gpioModePushPull, 1);
    delay_ms_cyc(10); // make sure LDO has time to start up (datasheet says 1ms startup time is typical, so 10 is more than enough)
    sensor_init();
    delay_ms_cyc(100); // sensor requires 100ms initial startup time.

    // Turn the sensor on and give it time to wake up from standby.
    sensor_turn_on(GAIN_1X);
    delay_ms_cyc(10);

    // Get the raw sensor reading.
    int32_t gain, itime;
    SEGGER_RTT_printf(0, "Waiting for sensor\n");
    sensor_wait_till_ready();
    SEGGER_RTT_printf(0, "Sensor ready\n");
    sensor_reading sr = sensor_get_reading_auto(&gain, &itime);
    g_state.last_reading = sr;
    g_state.last_reading_itime = itime;
    g_state.last_reading_gain = gain;

    // Convert the raw reading to an EV value.
    int32_t lux = sensor_reading_to_lux(sr, gain, itime);
    int32_t ev = lux_to_reflective_ev(lux);
    g_state.last_reading_ev = ev;
    SEGGER_RTT_printf(0, "READING g=%u itime=%u c0=%u c1=%u lux=%u/%u (%u) ev=%s%u/%u (%u)\n", gain, itime, sr.chan0, sr.chan1, lux, 1<<EV_BPS, lux>>EV_BPS, sign_of(ev), iabs(ev), 1<<EV_BPS, ev>>EV_BPS);

    g_state.led_brightness_ev_ref = ev;

    // Turn the LDO off to power down the sensor.
    GPIO_PinModeSet(REGMODE_PORT, REGMODE_PIN, gpioModeInput, 0);

    remove_rtc_interrupt_handler(display_reading_interrupt_cycle_interrupt_handler);
    leds_all_off();

    // If they're still holding down the button, display the reading
    // indefinitely until the button is released, then go into the
    // regular display reading mode.
    setup_capsense();
    uint32_t chans[] = { 0, 0, 0 };
    do {
        delay_ms_cyc_prepare {
            get_touch_count(0, 0, 0); // clear any nonsense value
        }
        uint32_t ellapsed = delay_ms_cyc_loop(PAD_COUNT_MS);
        uint32_t count, chan;
        get_touch_count(&count, &chan, ellapsed);
        chans[chan] = count;
        cycle_capsense();
    } while (chans[0] == 0 || chans[1] == 0 || chans[2] == 0);
    if (get_touch_position(chans[0], chans[1], chans[2]) == CENTER_BUTTON) {
        int32_t iso = iso_dial_pos_and_third_to_iso(g_state.iso_dial_pos, g_state.iso_third);
        int ap_index, ss_index, third;
        ev_iso_aperture_to_shutter(g_state.last_reading_ev, iso, g_state.last_ap, &ap_index, &ss_index, &third);
        SEGGER_RTT_printf(0, "Third: %s%u\n", sign_of(third), iabs(third));
        set_led_throb_mask(0);
        set_led_flash_mask(0);
        leds_on(led_mask_for_reading(ap_index, ss_index, third));

        chans[0] = 0, chans[1] = 0, chans[2] = 0;
        int misses = 0;
        for (;;) {
            delay_ms_cyc_prepare {
                get_touch_count(0, 0, 0); // clear any nonsense value
            }
            uint32_t ellapsed = delay_ms_cyc_loop(PAD_COUNT_MS);
            uint32_t count, chan;
            get_touch_count(&count, &chan, ellapsed);
            chans[chan] = count;

            if (chans[0] != 0 && chans[1] != 0 && chans[2] != 0) {
                if (get_touch_position(chans[0], chans[1], chans[2]) != CENTER_BUTTON) {
                    ++misses;
                    if (misses >= MISSES_REQUIRED_TO_BREAK_HOLD)
                        break;
                } else {
                    misses = 0;
                }
            }

            cycle_capsense();
        }
    }

    leds_all_off();
    disable_capsense();

    g_state.mode = MODE_DISPLAY_READING;
}
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
int main()
{
    // We have to do without the chip errata as running this after every watchdog reset
    // in deep sleep mode consumes too much current. I've verified that this function
    // doesn't do anything that we need.
    //
    // CHIP_Init();

#if defined(TEST_MAIN) || defined(DISABLE_DEEP_SLEEP)
    bool watchdog_wakeup = false;
#else
    uint32_t reset_cause = RMU_ResetCauseGet();
    RMU_ResetCauseClear();
    bool watchdog_wakeup = ((reset_cause & RMU_RSTCAUSE_WDOGRST) != 0);
#endif

    common_init(watchdog_wakeup);

#ifdef TEST_MAIN
    return test_main();
#else
    return real_main(watchdog_wakeup);
#endif
}

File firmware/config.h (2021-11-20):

#ifndef CONFIG_H
#define CONFIG_H

// Define this to disable deep sleep mode. Recommended, as it doesn't seem to be
// very successful in reducing power consumption over the regular sleep mode,
// and may occasionally cause startup issues with the boost converter.
#define DISABLE_DEEP_SLEEP

#define NORMAL_PAD_SCAN_HZ                                  45
#define SLOW_PAD_SCAN_HZ                                    1

#define LONG_PRESS_MS                                       300
#define ISO_LONG_PRESS_MS                                   600
#define DOUBLE_BUTTON_SLOP_MS                               300
#define CENTER_BUTTON_DEAD_ZONE_MS                          200

#define LE_CAPSENSE_CALIBRATION_INTERVAL_SECONDS            10
#define DEEP_SLEEP_TIMEOUT_SECONDS                          (1*60*60)
#define DEEP_SLEEP_TIMEOUT_SECONDS_DEBUG_MODE               20
#define LE_CAPSENSE_DEEP_SLEEP_CALIBRATION_INTERVAL_SECONDS 30

#define MISSES_REQUIRED_TO_BREAK_HOLD                       2

#define DISPLAY_READING_TIME_SECONDS                        20

// You'll need to tweak the logic in
// display_reading_interrupt_cycle_interrupt_handler in main.c if you change
// this.
#define LED_REFRESH_RATE_HZ                                 1200
#define CYCLES_PER_COUNTER_DECREMENT                        4

// Length of the grace period prior to capsense calibration.
#define GRACE_PERIOD_SECONDS                                8

// This is the value for a 2mm thick transparent acrylic window.
#define WINDOW_ATTENUATION_STOPS                            0.1586

#define WINDOW_FOV_ATTENUATION_STOPS                        1.54

#endif

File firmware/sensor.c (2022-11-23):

#include <em_cmu.h>
#include <em_gpio.h>
#include <em_i2c.h>
#include <rtt.h>
#include <sensor.h>
#include <time.h>
#include <units.h>
#include <util.h>

#define SENSOR_I2C_PORT       gpioPortE
#define SENSOR_I2C_SDA_PIN    12
#define SENSOR_I2C_SCL_PIN    13

#define SENSOR_I2C_ADDR       (0x29 << 1)

void sensor_init()
{
    CMU_ClockEnable(cmuClock_I2C0, true);

    GPIO_PinModeSet(SENSOR_I2C_PORT, SENSOR_I2C_SCL_PIN, gpioModeWiredAndFilter, 1); // configure SCL pin as open drain output
    GPIO_PinModeSet(SENSOR_I2C_PORT, SENSOR_I2C_SDA_PIN, gpioModeWiredAndFilter, 1); // configure SDA pin as open drain output

    I2C0->ROUTE = I2C_ROUTE_SDAPEN | I2C_ROUTE_SCLPEN | (6 << _I2C_ROUTE_LOCATION_SHIFT);
    I2C0->CTRL = I2C_CTRL_AUTOACK | I2C_CTRL_AUTOSN;

    /* In some situations (after a reset during an I2C transfer), the slave */
    /* device may be left in an unknown state. Send 9 clock pulses just in case. */
    for (unsigned i = 0; i < 9; i++)
    {
        /*
         * TBD: Seems to be clocking at appr 80kHz-120kHz depending on compiler
         * optimization when running at 14MHz. A bit high for standard mode devices,
         * but DVK only has fast mode devices. Need however to add some time
         * measurement in order to not be dependable on frequency and code executed.
        */
        GPIO_PinModeSet(SENSOR_I2C_PORT, SENSOR_I2C_SCL_PIN, gpioModeWiredAndFilter, 0);
        GPIO_PinModeSet(SENSOR_I2C_PORT, SENSOR_I2C_SCL_PIN, gpioModeWiredAndFilter, 1);
    }

    I2C_Init_TypeDef i2c_init = {
        .enable = true,
        .master = true,
        .refFreq = 0,
        .freq = I2C_FREQ_STANDARD_MAX,
        .clhr = i2cClockHLRAsymetric
    };

    I2C_Init(I2C0, &i2c_init);
    NVIC_ClearPendingIRQ(I2C0_IRQn);
    NVIC_DisableIRQ(I2C0_IRQn);

    SEGGER_RTT_printf(0, "Light sensor initialization complete.\n");
}

void sensor_write_reg(uint16_t addr, uint8_t reg, uint8_t val)
{
    uint8_t wbuf[] = { reg, val };
    I2C_TransferSeq_TypeDef i2c_transfer = {
        .addr = addr,
        .flags = I2C_FLAG_WRITE,
        .buf[0].data = wbuf,
        .buf[0].len = 2
    };
    int status = I2C_TransferInit(I2C0, &i2c_transfer);
    while (status != i2cTransferDone) {
        status = I2C_Transfer(I2C0);
    }
}

uint8_t sensor_read_reg(uint16_t addr, uint8_t reg)
{
    return (uint8_t)(sensor_read_reg16(addr, reg) & 0xFF);
}

uint16_t sensor_read_reg16(uint16_t addr, uint8_t reg)
{
    uint8_t wbuf[1];
    wbuf[0] = reg;
    uint8_t rbuf[2];
    I2C_TransferSeq_TypeDef i2c_transfer = {
        .addr = addr,
        .flags = I2C_FLAG_WRITE_READ,
        .buf[0].data = wbuf,
        .buf[0].len = sizeof(wbuf)/sizeof(wbuf[0]),
        .buf[1].data = rbuf,
        .buf[1].len = sizeof(rbuf)/sizeof(rbuf[0])
    };
    int status = I2C_TransferInit(I2C0, &i2c_transfer);
    while (status == i2cTransferInProgress)
        status = I2C_Transfer(I2C0);
    return (uint16_t)rbuf[0] | ((uint16_t)rbuf[1] << 8);
}

sensor_reading sensor_get_reading()
{
    sensor_reading r;
    // The datasheet says that chan1 is to be read before chan0. This is
    // important for ensuring that the various status flags are correctly
    // reset following a read.
    r.chan1 = sensor_read_reg16(SENSOR_I2C_ADDR, REG_ALS_DATA_CH1_0);
    r.chan0 = sensor_read_reg16(SENSOR_I2C_ADDR, REG_ALS_DATA_CH0_0);

    return r;
}

bool sensor_has_valid_data()
{
    uint8_t status = sensor_read_reg(SENSOR_I2C_ADDR, REG_ALS_STATUS);
    return !(status & 0b10000000);
}

static void get_mode(sensor_reading r, int32_t *itime, int *itime_key, int32_t *gain, int *gain_key)
{
    int32_t lux50 = sensor_reading_to_lux(r, 1, 50);
    SEGGER_RTT_printf(0, "LUX50 = %u/%u = %u (c0=%u,c1=%u)\n", lux50, (1<<EV_BPS), lux50/(1<<EV_BPS), r.chan0, r.chan1);
    int32_t rat = ((int32_t)r.chan1 * 100) / ((int32_t)r.chan0 + (int32_t)r.chan1);

    static const int16_t itimes[] = {
        400, 350, 300, 250, 200, 150, 100, 50
    };
    static const int8_t gains[] = {
        48, 8, 4, 2, 1, 96
    };

    static const int64_t NOMINAL_MAX_CHAN = 6000;

    int i, j;
    if (rat >= 85) {
        i = sizeof(itimes)/sizeof(itimes[0]) - 1;
        j = 0;
    } else {
        // Figure out the longest possible itime we can use.
        // Could use a binary search here, but a linear search performs well enough.
        for (i = 0; i < sizeof(itimes)/sizeof(itimes[0]); ++i) {
            for (j = 0; j < sizeof(gains)/sizeof(gains[0]); ++j) {
                int64_t max;
                int64_t ch1 = (rat * NOMINAL_MAX_CHAN) / (100 - rat);
                if (rat < 45)
                    // * 10 because itime is in 100ths here, but 10ths in formula
                    max = ((17743*NOMINAL_MAX_CHAN + 11059*ch1) * 100) / (int64_t)gains[j] / (int64_t)itimes[i];
                else if (rat < 64)
                    max = ((42785*NOMINAL_MAX_CHAN - 19548*ch1) * 100) / (int64_t)gains[j] / (int64_t)itimes[i];
                else
                    max = ((5926*NOMINAL_MAX_CHAN + 1185*ch1) * 100) / (int64_t)gains[j] / (int64_t)itimes[i];

                // max is in lux*10000. Convert to 1 << EV_BPS
                // + 1 so that we get a slight underestimate rather than a slight overestimate.
                int32_t max32 = (int32_t)(max / (10000 / (1 << EV_BPS)) + 1);

                if (max32 > (lux50*11) / 10)
                    goto break_outer;
            }
        }
    }

break_outer:

    i %= sizeof(itimes)/sizeof(itimes[0]);
    if (j >= sizeof(gains)/sizeof(gains[0]))
        j = 4;

    *itime = itimes[i];
    *gain = gains[j];

    switch (i) {
        case 7:
            *itime_key = ITIME_50;
            break;
        case 6:
            *itime_key = ITIME_100;
            break;
        case 5:
            *itime_key = ITIME_150;
            break;
        case 4:
            *itime_key = ITIME_200;
            break;
        case 3:
            *itime_key = ITIME_250;
            break;
        case 2:
            *itime_key = ITIME_300;
            break;
        case 1:
            *itime_key = ITIME_350;
            break;
        case 0:
            *itime_key = ITIME_400;
            break;
        default:
            break;
    }

    switch (j) {
        case 0:
            *gain_key = GAIN_48X;
            break;
        case 1:
            *gain_key = GAIN_8X;
            break;
        case 2:
            *gain_key = GAIN_4X;
            break;
        case 3:
            *gain_key = GAIN_2X;
            break;
        case 4:
            *gain_key = GAIN_1X;
            break;
        case 5:
            *gain_key = GAIN_96X;
            break;
        default:
            break;
    }
}
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

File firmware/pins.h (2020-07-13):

#ifndef PINS_H
#define PINS_H

#define REGMODE_PORT                                        gpioPortF
#define REGMODE_PIN                                         2
#define BATSENSE_PORT                                       gpioPortC
#define BATSENSE_PIN                                        15

#endif

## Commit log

2018-12-14 Tweak diode silkscreen IDs
    [board.kicad_pcb]
2018-12-14 Add mpns; add note; bat sense cap 1u -> u1
    [board.sch]
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2018-12-14 another minor bom tweak
    [board.sch]
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2018-12-14 change inductor; add mounting holes
    [board.kicad_pcb, board.sch]
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2018-12-17 update obsolete switch mpn
    [board.sch]
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2018-12-18 initial work on new reg
    [board.sch]
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2018-12-18 initial work on boost layout
    [board.kicad_pcb, board.sch]
2018-12-18 more routing progress; tie i2c pullups to LDO supply
    [board.kicad_pcb, board.sch]
2018-12-18 routing for new design done
    [board.kicad_pcb, board.sch]
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2018-12-19 fix bat clip mpn
    [board.sch]
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2018-12-22 Alternate diode / non-diode slider pins
    [board.kicad_pcb, board.sch]
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2018-12-22 initial work on rewiring following crystal removal
    [board.kicad_pcb, board.sch]
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2018-12-24 Add resistors to schematic
    [board.sch]
2018-12-24 led series resistors nearly wired up
    [board.kicad_pcb, board.sch]
2018-12-24 finish wiring current limiting resistors
    [board.kicad_pcb]
2018-12-24 minor ground fill tweak
    [board.kicad_pcb]
2018-12-24 tidy a couple of traces
    [board.kicad_pcb]
2018-12-24 Fix DRC violation
    [board.kicad_pcb]
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2018-12-24 change handling of sensor interrupt
    [board.kicad_pcb, board.sch]
2018-12-24 change switch part and add missing footprints to repo
    [board.kicad_pcb]
2018-12-24 update part number on schematic
    [board.sch]
2018-12-25 finish routing regmode to new pin
    [board.kicad_pcb, board.sch]
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2018-12-25 initial thoughts on relocating battery
    [board.kicad_pcb]
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2018-12-25 adjust touch pad border
    [board.kicad_pcb]
2018-12-25 remove some unnecessary vias
    [board.kicad_pcb]
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2018-12-25 Fix soldermask clearance issues
    [board.kicad_pcb]
2018-12-26 Add some test points
    [board.kicad_pcb, board.sch]
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2018-12-26 some initial work on moving battery clip
    [board.kicad_pcb]
2018-12-26 Move bat clip again
    [board.kicad_pcb]
2018-12-26 finish moving bat clip
    [board.kicad_pcb]
2018-12-27 add testpad for pvreg
    [board.kicad_pcb, board.sch]
2018-12-28 beef up a power trace
    [board.kicad_pcb]
2018-12-28 minor silk screen edits
    [board.kicad_pcb]
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2018-12-28 add current sense resistor for testing.
    [board.kicad_pcb, board.sch]
2018-12-28 remove thing that would cause short
    [board.kicad_pcb]
2018-12-28 current sensing thing won't work
    [board.kicad_pcb, board.sch]
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2018-12-28 more ground plane work
    [board.kicad_pcb]
2018-12-29 minor layout tweak immediately following first jlpcb order
    [board.kicad_pcb]
2018-12-31 add battery reverse protection on high side (schematic only)
    [board.sch]
2018-12-31 add reverse polarity protection to board
    [board.kicad_pcb, board.sch]
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2019-01-15 attempted boost circuit fix
    [board.kicad_pcb, board.sch]
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2019-01-19 fix vreg circuit properly
    [board.kicad_pcb, board.sch]
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2019-01-23 fix gain setting bug
    [main.c, sensor.c, sensor.h]
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2019-02-07 corrected lux calc, but now have some minor precision issues
    [sensor.c, sensor.h]
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2019-02-10 some possible progress but weird c0 0 issue
    [main.c, sensor.c, sensor.h]
2019-02-10 Fix channel ready order issue
    [main.c, sensor.c, sensor.h]
2019-02-10 Fix confusing logging of negative values
    [main.c]
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2019-07-07 some board design tweaks and initial work on case.py
    [board.kicad_pcb, board.sch]
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2019-07-09 fix some calcs in unit; fix naming of 1/125 shutter speed
    [board.kicad_pcb]
2019-07-10 some work on plot_luxcalc.R and test data
    [board.sch]
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2019-07-15 board layout tweaks; remove bat warning led
    [board.kicad_pcb, board.sch]
2019-08-03 Fix device/Device naming issue in schematic file
    [board.sch]
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2019-08-05 board and cairo tweaks
    [board.kicad_pcb]
2019-08-07 increase mouting leg diam
    [board.kicad_pcb]
2019-08-07 drc and silkscreen tweaks; notes updates
    [board.kicad_pcb]
2019-08-07 minor change to board
    [board.kicad_pcb]
2019-08-09 tidy up ground polygon a bit
    [board.kicad_pcb]
2019-08-11 improve ground polygon connectivity
    [board.kicad_pcb, board.sch]
2019-08-11 fix drc issues
    [board.kicad_pcb]
2019-08-13 tighten up sensor startup delays
    [main.c]
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2019-08-13 more work on ground polygon connectivity
    [board.kicad_pcb]
2019-08-13 update some mpns for latest order
    [board.sch]
2019-08-14 update inductor value and MPN (package still needs updating)
    [board.sch]
2019-08-14 update buck inductor package
    [board.kicad_pcb, board.sch]
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2019-08-14 TEMP fixed footprints mess
    [board.kicad_pcb, board.sch]
2019-08-14 TEMP add missing footprints
2019-08-14 fix silkscreen
    [board.kicad_pcb]
2019-08-14 add prot resistor for button
    [board.kicad_pcb, board.sch]
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2019-08-15 TEMP led issue
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2019-08-18 make appropriate use of sensor standby to prevent corrupted readings
    [sensor.c, sensor.h]
2019-08-18 fix some rtc issues; test code for led cycling glitch
    [leds.c, main.c]
2019-08-19 bugs in led code fixed; basic wheel scrolling now working
    [leds.c, main.c]
2019-08-21 Remove potential shorts under battery
    [board.kicad_pcb]
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2019-08-21 get board back to sane state
    [board.kicad_pcb, board.sch]
2019-08-21 remove shorting hazards under battery
    [board.kicad_pcb]
2019-08-22 crash in test for very high reading
    [main.c]
2019-08-22 fix bug that could cause sensor_get_reading_auto to hang
    [sensor.c]
2019-08-22 fix led flicker bug
    [leds.c, main.c]
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2019-08-26 make switch defaults available by omitting switches and diodes
    [board.kicad_pcb, board.sch]
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2019-08-26 swap s1 and s3 to simplify connections
    [board.kicad_pcb]
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2019-09-08 basic metering functionality now working (with possible miscalibration)
    [board.kicad_pcb]
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2019-09-08 FLIPPED DIODES
    [board.kicad_pcb]
2019-09-08 TEMP reversed silkscreen and third leds
    [board.kicad_pcb]
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2019-10-26 DRC and S1/S2 swap
    [board.kicad_pcb, board.sch]
2019-10-26 replace pushbutton with touch pad (as yet unconnected)
    [board.kicad_pcb, board.sch]
2019-10-27 Revert "replace pushbutton with touch pad (as yet unconnected)"
    This reverts commit fc872448d75c29a03683245fcbd4d669ef47c021.
    [board.kicad_pcb, board.sch]
2019-10-27 switch to thicker pushbutton mounted on top side
    [board.kicad_pcb, board.sch]
2019-10-27 change mpn for cr2032 rather than thinner coin cell
    [board.sch]
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2019-11-02 remove mounting holes and tidy up a trace
    [board.kicad_pcb]
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2019-11-03 go back to using zener and gpio pin for batvolt sensing
    [board.kicad_pcb, board.sch]
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2019-11-04 move sensor equal distance from both board edges
    [board.kicad_pcb]
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2019-11-09 fix MPN for schotkey diodes
    [board.sch]
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2019-11-12 rough work on modifying touch code for two touch buttons
    [board.kicad_pcb]
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2019-11-14 fix button gpio state
    [main.c]
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2019-11-16 fix led numbering
2019-11-16 fix exposure display logic
    [main.c]
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2019-11-17 fix touch wheel changes
    [capsense.c, main.c]
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2019-11-17 move sensor bypass cap to more sensible location
    [board.kicad_pcb]
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2019-11-18 fix bugs in iso setting
    [main.c]
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2019-11-21 fix some sleep-related issues
    [main.c]
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2019-11-23 use different battery protection mosfet (lower leakage current)
    [board.kicad_pcb]
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2019-11-23 add missing kicad_mode files
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2019-11-23 Revert "remove experimental capsense le code for now"
    This reverts commit bfe4b6ab27654f5075d681d799d0b43455038417.
    [board.sch]
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2019-12-08 fix light sensor routing
    [board.kicad_pcb]
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2019-12-09 add missing trace
    [board.kicad_pcb]
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2019-12-18 Add missing mpn for side switch
    [board.sch]
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2019-12-18 not getting correct readings for center pad yet..
    [capsense.c, main.c]
2019-12-18 get touch detection working correctly on all three pads
    [capsense.c]
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2019-12-20 tap vs hold detection more or less working
    [board.kicad_pcb]
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2019-12-21 Revert "abbortive double tap work"
    This reverts commit bcd8a889e0dfefd63bfc5e2b40ae293078c98c6f.
    [capsense.c, config.h, main.c]
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2019-12-21 fix wheel logic
2019-12-21 redesign bat neg pad
    [board.kicad_pcb]
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2019-12-27 fix light show logic
    [main.c]
2019-12-27 weird no-op bug fix for throb
    [leds.c, main.c]
2019-12-30 add circular keepout zones for leds, and gen script
    [board.kicad_pcb]
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2020-01-11 some changes to improve perf with partially discharged batteries
    [board.kicad_pcb, board.sch]
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2020-01-12 add missing MPN field
    [board.sch]
2020-01-12 correct mpns
    [board.sch]
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2020-01-12 fix temp sensor reading code
    [main.c, sensor.c]
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2020-01-18 fix build issue caused by missing include
    [tempsensor.c]
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2020-01-26 fix drc
    [board.kicad_pcb]
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2020-02-16 fixes to code for new board
    [batsense.c, config.h, leds.h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]
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2020-02-25 fix reflective/incident mixup responsible for overestimating required exposure
    [main.c]
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2020-03-08 code for setting iso dial now in working state again
    [board.kicad_pcb]
2020-03-08 fix stupid led bug
    [leds.h, main.c]
2020-03-17 fixes to watchdog test code
    [init.c, main.c]
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2020-03-21 fix off by factor of 10 error in calc
    [sensor.c]
2020-03-22 fix some nasty overflow issues
    [sensor.c]
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2020-04-03 add missing call to remove_interrupt_handler(display_reading_interrupt_cycle_interrupt_handler);
    [main.c]
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2020-04-10 fix some counter overflow bugs
    [main.c]
2020-04-21 fix some DEBUG/TEST and sleep mode mixups
    [main.c]
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2020-04-21 fixes to reset test
    [main.c]
2020-04-23 fix some bad timer count logic
    [capsense.c]
2020-04-26 no vias near IC - potential for light leaks
    [board.kicad_pcb]
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2020-04-30 move resistors a little further from prog connector pads
    [board.kicad_pcb]
2020-05-02 fix issues with deep sleep wakeup
    [init.c, main.c]
2020-05-03 flip sensor to landscape orientation
    [board.kicad_pcb]
2020-05-03 Revert "remove gotos" (seems to have introduced subtle bugs)
    This reverts commit 7c52076fc39e1ca2944deef40f040b6ea77dc978.
    [main.c]
2020-05-03 fix some touch count bugs
    [capsense.c, main.c]
2020-05-04 fix various touch count issues
    [capsense.c, main.c, sensor.c]
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2020-05-08 use IC designator for op amp and LDO
    [board.kicad_pcb, board.kicad_sch]
2020-05-08 ger rid of stupid schematic border, as far as possible
    [board.kicad_sch]
2020-05-08 enter correct value for shunt resistor
    [board.kicad_sch]
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2020-05-08 fix angle of third LEDs and add arrows on silkscreen
    [board.kicad_pcb]
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2020-05-10 better fix for the CYCCNT bug
    [capsense.c, init.c, main.c]
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2020-05-16 fix display of long shutter speeds
    [leds.c, main.c]
2020-05-17 Bug fix for spurious touch wakeup following watchdog reset
    [capsense.c, config.h, main.c]
2020-05-21 fix slight misalignment of sensor
    [board.kicad_pcb]
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2020-05-21 fix wrong mpn
    [board.kicad_sch]
2020-05-21 fix wrong mpns
    [board.kicad_sch]
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2020-05-22 give visual feedback when limits of wheel cycle reached
    [board.kicad_pcb]
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2020-05-23 fix watchdog reset regression
    [init.c]
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2020-05-27 fix stupid circuit bug
    [board.kicad_pcb, board.kicad_sch]
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2020-05-30 accurate battery voltage measurements; put DPINs back to correct states
    [batsense.c, main.c]
2020-05-30 add missing call to disable_capsense
    [capsense.c]
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2020-05-30 correct mpns for 23.2 ohm resistors
    [board.kicad_sch]
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2020-06-06 add STL file for case; add dimensions to Readme
    [case.stl]
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2020-06-26 fix duty cycle logic
    [leds.c]
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2020-07-04 add missing MAN fields
    [board.kicad_sch]
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2021-07-10 zone fill issues
    [board.kicad_pcb, board.kicad_sch]
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2021-07-10 cut out bottom solder mask as well as copper layer over leds
    [board.kicad_pcb]
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2021-07-10 add missing connection
    [board.kicad_pcb]
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2021-07-10 fix some issues with keepout zone; stop via crossing shutter speed num
    [board.kicad_pcb]
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2021-07-10 fix some mpn metadata
    [board.kicad_sch]
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2021-07-10 fix code in test
    [sensor.c]
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2021-07-10 inserting battery wrong way round could now potentially damage the meter
2021-11-04 remove some debug logging that's no longer very useful
    [main.c]
2021-11-05 fix deep sleep bugs and add note to manual
    [capsense.c, config.h, main.c]
2021-12-03 Revert "remove some unnecessary gotos"
    This reverts commit ab844dbc5f042ceeaff656e032a1d13a8df954d7.
    [main.c]
2022-08-12 fix logic bug in sleep
    [main.c]
